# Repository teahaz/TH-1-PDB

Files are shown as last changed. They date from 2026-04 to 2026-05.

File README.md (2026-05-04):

# TH-1/PDB

An NRF52840 development board which fits into a framework compatible expansion slot. Designed to be a prototype for the TH-1 coprocessor.

> Teahaz 1: Prototype Development Board

---

# Version 1

> PDB adapted to fit inside a Framework compatible expansion card.
> This version is not complete or tested yet.





# Version 0

>  A quick and dirty implementation to check wether the NRF module works and is manufacturable (by me at home)





> (it worked)

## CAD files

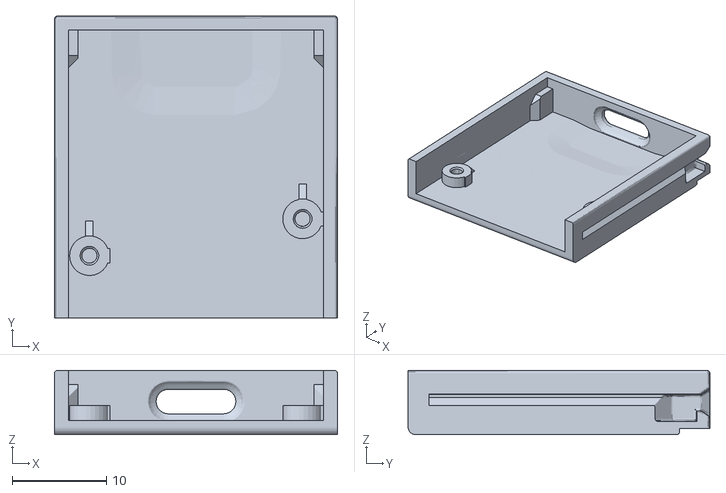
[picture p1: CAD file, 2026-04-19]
3D_models/FW_port_case.stl
30.0 x 32.0 x 6.80

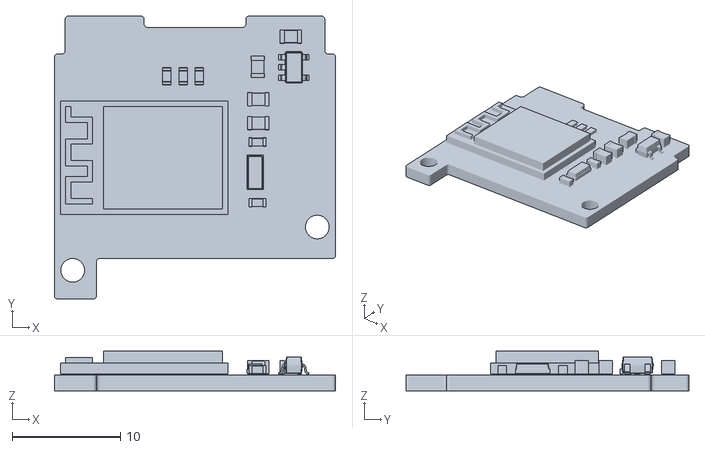
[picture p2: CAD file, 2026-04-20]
fab/nrfdevboard.stl
26.0 x 26.1 x 3.66

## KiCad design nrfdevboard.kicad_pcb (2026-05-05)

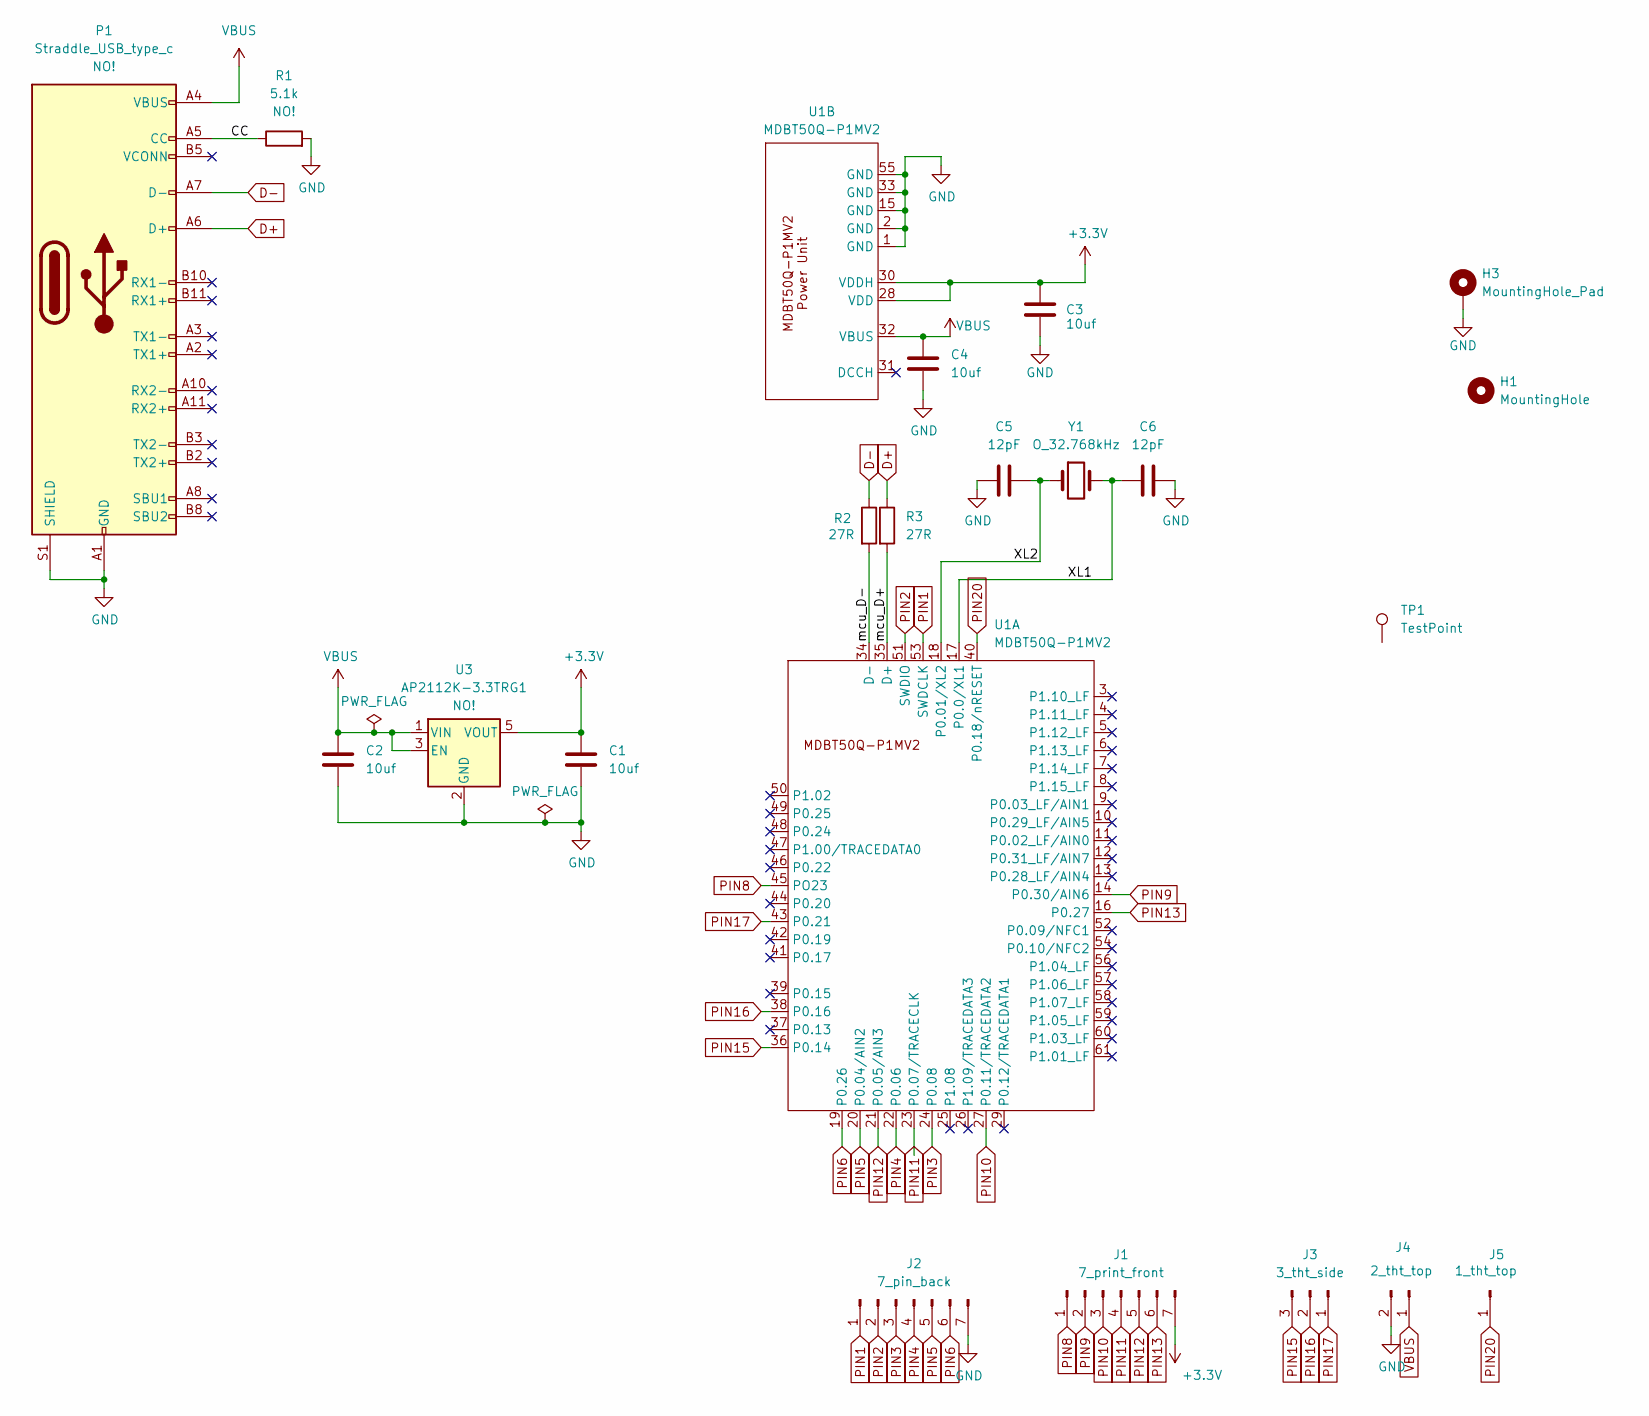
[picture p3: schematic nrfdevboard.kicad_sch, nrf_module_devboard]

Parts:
C1, C2, C3, C4: 10uf; C_0805_2012Metric; Mfr. Part no. CL21B106KOQNNNE; LCSC Part no. C95841
C5, C6: 12pF; C_0603_1608Metric; Mfr. Part no. CL10C120JB8NNNC; LCSC Part no. C38523
H1: MountingHole; PDB_MountingHole_left_2.2mm_M2
H3: MountingHole_Pad; PDB_MountingHole_right_2.2mm_M2_Pad
J1: 7_print_front; 7_side_pin
J2: 7_pin_back; 7_side_pin
J3: 3_tht_side; PinHeader_1x03_P2.54mm_Vertical
J4: 2_tht_top; PinHeader_1x02_P2.54mm_Vertical
J5: 1_tht_top; PinHeader_1x01_P2.54mm_Vertical
P1: Straddle_USB_type_c; USBC; Mfr. Part no. TYPE-C 24P-GTJB 040; LCSC Part no. C3151751
R1: 5.1k; R_0603_1608Metric; Mfr. Part No. RT0603BRD075K1L; LCSC Part no. C122969
R2, R3: 27R; R_0603_1608Metric; Mfr. Part No. 0603WAF270JT5E; LCSC Part no. C25190
TP1: TestPoint
U1: MDBT50Q-P1MV2; TH_MDBT50Q-P1MV2; Mfr Part no. MDBT50Q-P1MV2; LCSC Part no. C5119772
U3: AP2112K-3.3TRG1; SOT-23-5; Mfr. Part no. AP2112K-3.3TRG1; LCSC Part no. C23380830
Y1: O_32.768kHz; Crystal_SMD_3215-2Pin_3.2x1.5mm; Mfr. Part no. Q13FC13500003; LCSC Part no. C99010

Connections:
+3.3V: C1.1, C3.1, J1.7, U1.28 (VDD), U1.30 (VDDH), U3.5 (VOUT)
/CC: P1.A5 (CC), R1.1
/XL1: C6.1, U1.17 (P0.0/XL1), Y1.2
/XL2: C5.2, U1.18 (P0.01/XL2), Y1.1
/mcu_D+: R3.2, U1.35 (D+)
/mcu_D-: R2.2, U1.34 (D-)
D+: P1.A6 (D+), R3.1
D-: P1.A7 (D-), R2.1
GND: C1.2, C2.2, C3.2, C4.2, C5.1, C6.2, H3.1, J2.7, J4.2, P1.A1 (GND), P1.A12 (GND), P1.B1 (GND), P1.B12 (GND), P1.S1 (SHIELD), R1.2, U1.1 (GND), U1.2 (GND), U1.15 (GND), U1.33 (GND), U1.55 (GND), U3.2 (GND)
PIN1: J2.1, U1.53 (SWDCLK)
PIN2: J2.2, U1.51 (SWDIO)
PIN3: J2.3, U1.24 (P0.08)
PIN4: J2.4, U1.22 (P0.06)
PIN5: J2.5, U1.20 (P0.04/AIN2)
PIN6: J2.6, U1.19 (P0.26)
PIN8: J1.1, U1.45 (PO23)
PIN9: J1.2, U1.14 (P0.30/AIN6)
PIN10: J1.3, U1.27 (P0.11/TRACEDATA2)
PIN11: J1.4, U1.23 (P0.07/TRACECLK)
PIN12: J1.5, U1.21 (P0.05/AIN3)
PIN13: J1.6, U1.16 (P0.27)
PIN15: J3.3, U1.36 (P0.14)
PIN16: J3.2, U1.38 (P0.16)
PIN17: J3.1, U1.43 (P0.21)
PIN20: J5.1, U1.40 (P0.18/nRESET)
VBUS: C2.1, C4.1, J4.1, P1.A4 (VBUS), P1.A9 (VBUS), P1.B4 (VBUS), P1.B9 (VBUS), U1.32 (VBUS), U3.1 (VIN), U3.3 (EN)

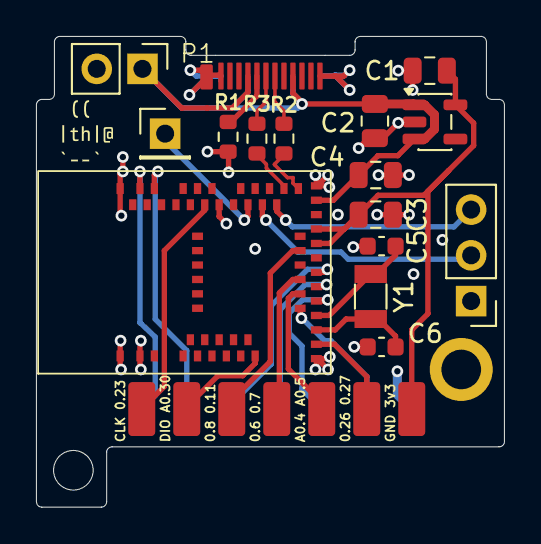
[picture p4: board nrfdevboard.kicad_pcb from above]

Board: 4 copper layers, 26.0 x 26.2 mm, 20 parts (1 on the bottom side), 26 nets.

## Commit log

2026-03-28 Finished p1
    [nrfdevboard.kicad_pcb, nrfdevboard.kicad_sch]
2026-03-28 Teardrops and grid origins.
    [nrfdevboard.kicad_pcb]
2026-04-19 PDBv2: Redesign for a framework module
    V2 brings two main changes. Firstly the size has been greatly reduced to
    fit into a framework module. With only 7 pins now.
    Additionally, v1 had issues when running from 5v USB. I am still not
    sure what this issue is since its identical to the datasheet, but I'm
    now including an external voltage regulator to run the chip at 3v3. This
    also reduces the BOM.
    [nrfdevboard.kicad_pcb, nrfdevboard.kicad_sch, nrfdevboard.stl]
2026-04-19 Minor tweaks
    [nrfdevboard.kicad_pcb, nrfdevboard.kicad_sch]
2026-04-19 Add fw expansion case and proper usbc footprint
    [FW_port_case.stl, nrfdevboard.kicad_pcb, nrfdevboard.kicad_sch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]
2026-04-20 Initial routing + 7 more GPIO pins
    [nrfdevboard.kicad_pcb, nrfdevboard.kicad_sch, nrfdevboard.stl]
2026-04-21 Routing done (outside USB) + added some more pins
    [nrfdevboard.kicad_pcb, nrfdevboard.kicad_sch]
2026-04-22 Basics done. Will need to optimise double check DFM before manufacturing
    [nrfdevboard.kicad_pcb, nrfdevboard.kicad_sch]
2026-05-04 Clearing up DRC errors (part 1)
    [nrfdevboard.kicad_pcb, nrfdevboard.kicad_sch]
2026-05-05 Fixed remaining DRC errors
    [nrfdevboard.kicad_pcb]
